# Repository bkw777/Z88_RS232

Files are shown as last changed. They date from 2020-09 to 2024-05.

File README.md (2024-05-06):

# Cambridge Z88 serial port adapters

## PC style
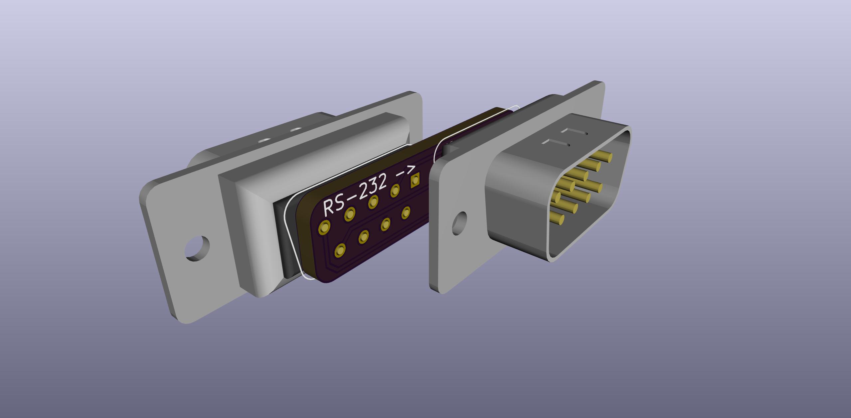
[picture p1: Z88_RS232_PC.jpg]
  


PCB: https://oshpark.com/shared_projects/w1GYezbu  
BOM: https://www.digikey.com/short/zfdrnv

Z88_RS232_PC converts the Z88 serial port to a PC style com port.  
DE9M with standard RS-232 DTE pinout.

This adapter is most convenient for using peripherals designed for use with a standard PC or USB-Serial adapter, or a 9-pin null-modem cable to a PC.

## "Model T" style
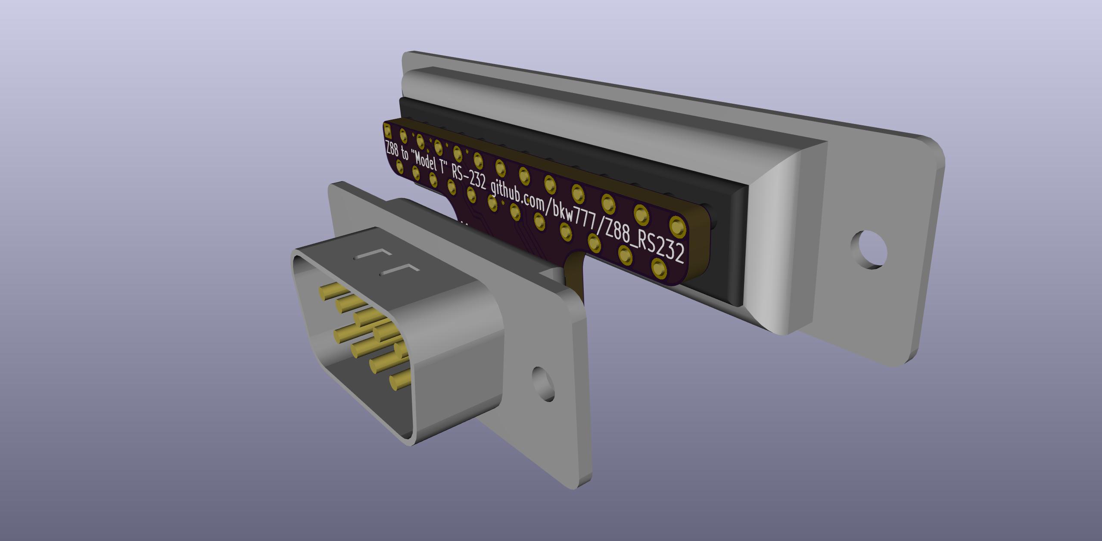
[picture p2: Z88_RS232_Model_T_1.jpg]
  
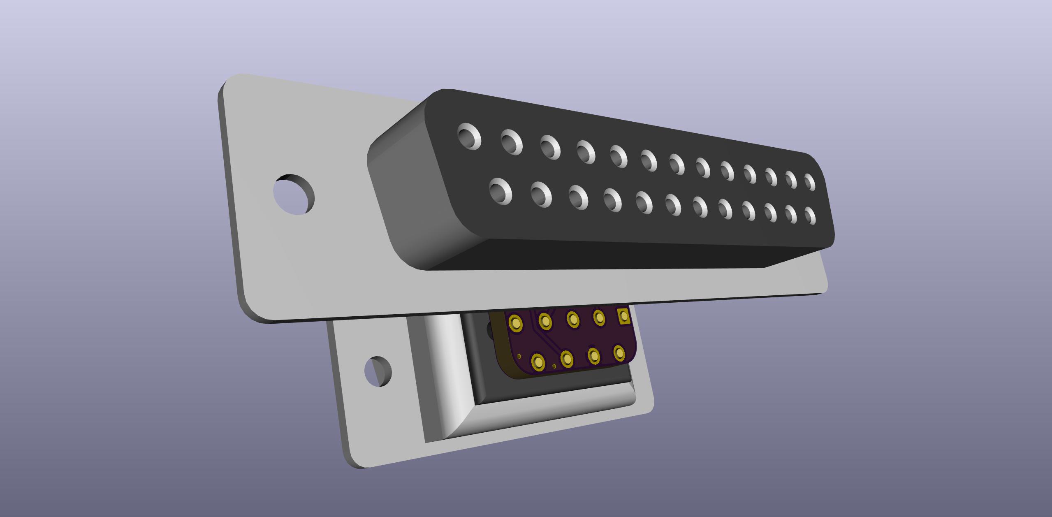
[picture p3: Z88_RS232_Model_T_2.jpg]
  


PCB: https://oshpark.com/shared_projects/cCj4Skb4  
BOM: https://www.digikey.com/short/zfdrnz

Z88_RS232_Model_T converts the Z88 serial port to a "Model T" style serial port.  
DB25F with standard RS-232 DTE pinout.

This is not like most hosts or devices today, in that normally a DTE or host port is a male plug, but it's otherwise still conforming to the rs232 standard in that the correct rs-232 signals are on the correct pin numbers. It's only the female connector that's unusual.

"Model T" computers are: TRS-80/TANDY Models 100, 102, 200, 600, NEC Models PC-8201, PC-8201A, PC-8300, Olivetti M10, and Kyotronic KC-85. All of these machines have a DB25F connectore with a RS-232 DTE pinout.

This adapter is most convenient for using peripherals designed for use with "Model T" computers, for instance the Tandy Portable Disk Drive.

You could connect to a PC with this adapter too, by using the same slightly uncommon kind of cable that a "model T" would need.  
http://tandy.wiki/Model_T_Serial_Cable

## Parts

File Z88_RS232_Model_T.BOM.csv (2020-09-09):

Index | Quantity | Part Number | Manufacturer Part Number | Description | Customer Reference | Available | Backorder | Unit Price | Extended Price USD
1 | 1 | AE10973-ND | A-DS 09 PP/Z | CONN D-SUB PLUG 9POS VERT SOLDER |  | 1 | 0 | 0.67000 | 0.67
2 | 1 | AE10940-ND | A-DF 25 PP/Z | CONN D-SUB RCPT 25POS VERT SLDR |  | 1 | 0 | 1.16000 | 1.16

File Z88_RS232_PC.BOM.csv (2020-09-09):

Index | Quantity | Part Number | Manufacturer Part Number | Description | Customer Reference | Available | Backorder | Unit Price | Extended Price USD
1 | 2 | AE10973-ND | A-DS 09 PP/Z | CONN D-SUB PLUG 9POS VERT SOLDER |  | 2 | 0 | 0.67000 | 1.34

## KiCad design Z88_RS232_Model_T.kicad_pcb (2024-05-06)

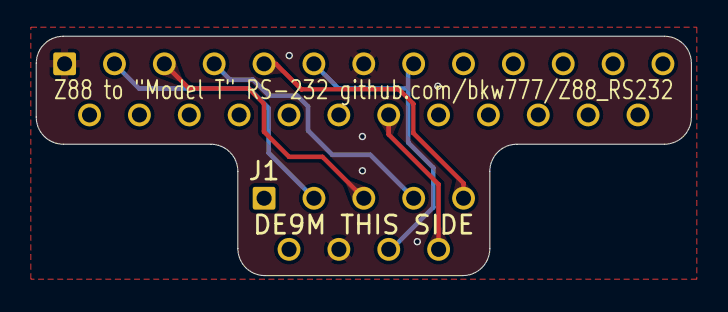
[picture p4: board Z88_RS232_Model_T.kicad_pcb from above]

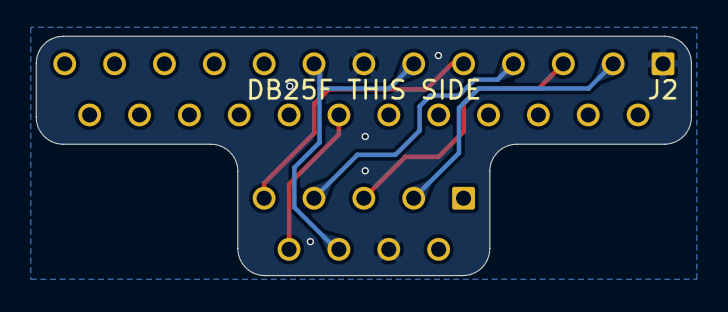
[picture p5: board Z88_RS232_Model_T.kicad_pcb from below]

Board: 2 copper layers, 36.4 x 13.3 mm, 3 parts (2 on the bottom side), 8 nets.

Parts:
J1: DE9_Male; DSUB-9_Male_Vertical_P2.77x2.84mm
J2: DB25 Female; DSUB-25_Female_Vertical_P2.77x2.84mm
NT1: Net-Tie_2; NetTie-2_SMD_10

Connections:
/CTS: J1.5, J2.5
/DCD: J1.8, J2.8, NT1.1
/DSR: J2.6, NT1.2
/DTR: J1.9, J2.20
/RTS: J1.4, J2.4
/RX: J1.3, J2.3
/TX: J1.2, J2.2
GND: J1.7, J2.1, J2.7

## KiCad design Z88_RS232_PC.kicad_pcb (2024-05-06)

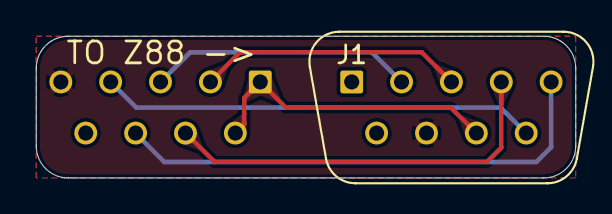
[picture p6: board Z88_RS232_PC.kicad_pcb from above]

Board: 2 copper layers, 30.0 x 7.9 mm, 3 parts (1 on the bottom side), 8 nets.

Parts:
J1, J2: DE9_Male; DSUB-9_Male_Vertical_P2.77x2.84mm
NT1: Net-Tie_2; NetTie-2_SMD_10

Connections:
/CTS: J1.5, J2.8
/DCD: J1.8, J2.1, NT1.1
/DSR: J2.6, NT1.2
/DTR: J1.9, J2.4
/RTS: J1.4, J2.7
/RX: J1.3, J2.2
/TX: J1.2, J2.3
GND: J1.7, J2.5

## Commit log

2020-09-09 pcbs & boms
    [Z88_RS232_Model_T.BOM.csv, Z88_RS232_PC.BOM.csv]
2024-05-06 kicad8, increase model-t pcb size
    [Z88_RS232_Model_T.kicad_pcb, Z88_RS232_Model_T.kicad_sch, Z88_RS232_Model_T.sch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]
